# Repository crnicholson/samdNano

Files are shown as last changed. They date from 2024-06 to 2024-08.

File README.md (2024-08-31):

# samdNano+

samdNano+ PCB

The samdNano+ is based on the Arduino Nano board. The format was extended to allow for more pins to be broken out. It uses the powerful SAMD21G18A chip that is significantly faster and more powerful than the Arduino Nano. It boasts extra pins just for SPI and I2C, while additionally the option to disable LEDs and the power regulator for ultra-low power performance. 

# License

samdNano+ is licensed under the CERN Open Hardware Licence Version 2 - Strongly Reciprocal to allow to modify it and make their own.

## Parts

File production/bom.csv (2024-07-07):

Designator | Footprint | Quantity | Value | LCSC Part #
C1, C3, C4, C7, C8 | 0402 | 5 | 100 nF | C1525
C10, C9 | 0805 | 2 | 10 uF | C15850
C2 | 0603 | 1 | 1 uF | C15849
C5, C6 | 0402 | 2 | 22 pF | C1555
D1 | 0805 | 1 | PWR_LED | C84256
D2 | 0603 | 1 | LED | C72038
J1 | PinHeader_2x05_P1.27mm_Vertical_SMD | 1 | J Link
J2 | USB_C_Receptacle_GCT_USB4105-xx-A_16P_TopMnt_Horizontal | 1 | USB-C | C136423
J3 | PinHeader_1x18_P2.54mm_Vertical | 1 | Digital
J4 | PinHeader_1x18_P2.54mm_Vertical | 1 | Analog
JP1 | SolderJumper-2_P1.3mm_Open_RoundedPad1.0x1.5mm | 1 | PWR_EN
JP2 | SolderJumper-2_P1.3mm_Open_RoundedPad1.0x1.5mm | 1 | PWR_LED_EN
JP3 | SolderJumper-2_P1.3mm_Open_RoundedPad1.0x1.5mm | 1 | LED_EN
R1, R2 | 0603 | 2 | 1.8 K | C4177
R3, R5 | 0402 | 2 | 5.1 K | C25905
R4 | 0402 | 1 | 220 | C25091
R6, R7 | 0402 | 2 | 1 K | C11702
SW1 | SW_SPST_CK_RS282G05A3 | 1 | RESET | C2888954
U1 | SOT-223-3_TabPin2 | 1 | AMS1117-3.3 | C6186
U2 | TQFP-48_7x7mm_P0.5mm | 1 | ATSAMD21G18A-A | C78624
Y1 | XTAL_CM7V-T1A-32.768K-12.5PF-20PPM-TA-QA | 1 | 32.768 kHz | C32346

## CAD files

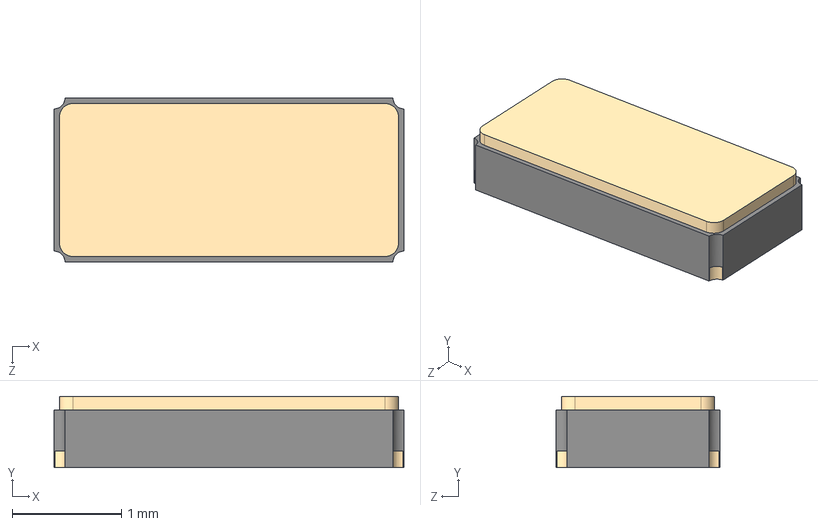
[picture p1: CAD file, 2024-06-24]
CM7V-T1A-32.768K-12.5PF-20PPM-TA-QA/CM7V-T1A-32.768K-12.5PF-20PPM-TA-QA.step
3.20 x 0.65 x 1.50 mm

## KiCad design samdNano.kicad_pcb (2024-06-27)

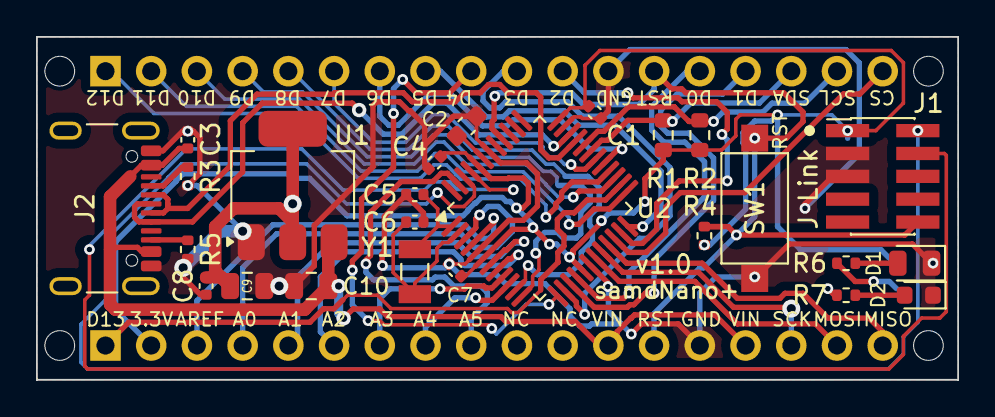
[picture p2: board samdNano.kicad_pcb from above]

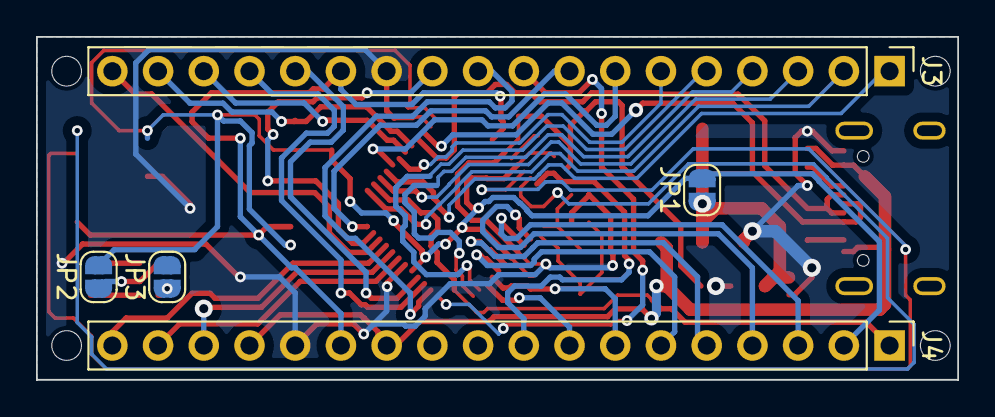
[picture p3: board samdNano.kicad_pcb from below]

Board: 2 copper layers, 51.2 x 19.1 mm, 34 parts (5 on the bottom side), 45 nets.

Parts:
C1, C3, C4, C7, C8: 100 nF; C_0402_1005Metric
C2: 1 uF; C_0603_1608Metric
C5, C6: 22 pF; C_0402_1005Metric
C9, C10: 10 uF; C_0805_2012Metric
D1: PWR_LED; LED_0805_2012Metric
D2: LED; LED_0603_1608Metric
J1: J Link; PinHeader_2x05_P1.27mm_Vertical_SMD
J2: USB-C; USB_C_Receptacle_GCT_USB4105-xx-A_16P_TopMnt_Horizontal
J3: Digital; PinHeader_1x18_P2.54mm_Vertical
J4: Analog; PinHeader_1x18_P2.54mm_Vertical
JP1: PWR_EN; SolderJumper-2_P1.3mm_Open_RoundedPad1.0x1.5mm
JP2: PWR_LED_EN; SolderJumper-2_P1.3mm_Open_RoundedPad1.0x1.5mm
JP3: LED_EN; SolderJumper-2_P1.3mm_Open_RoundedPad1.0x1.5mm
MH1, MH2, MH3, MH4: MountingHole_65mil
R1, R2: 1.8 K; R_0603_1608Metric
R3, R5: 5.1 K; R_0402_1005Metric
R4: 220; R_0402_1005Metric
R6, R7: 1 K; R_0402_1005Metric
SW1: RESET; SW_SPST_CK_RS282G05A3
U1: AMS1117-3.3; SOT-223-3_TabPin2
U2: ATSAMD21G18A-A; TQFP-48_7x7mm_P0.5mm
Y1: 32.768 kHz; XTAL_CM7V-T1A-32.768K-12.5PF-20PPM-TA-QA

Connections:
+3.3V: C1.1, C4.2, C7.1, J1.1, J4.2, JP1.2 (B), JP2.2 (B), R1.2, R2.2, R4.1, U2.6 (VDDANA), U2.17 (VDDIO), U2.36 (VDDIO), U2.44 (VDDIN)
+5V: C3.1, C10.1, J2.A4 (VBUS), J2.A9 (VBUS), J2.B4 (VBUS), J2.B9 (VBUS), J4.12, J4.15, U1.3 (VI)
A0: J4.4, U2.3 (PA02)
A1: J4.5, U2.7 (PB08)
A2: J4.6, U2.8 (PB09)
A3: J4.7, U2.9 (PA04)
A4: J4.8, U2.10 (PA05)
A5: J4.9, U2.47 (PB02)
AREF: J4.3, U2.4 (PA03)
CS: J3.18, U2.22 (PA13)
D0: J3.14, U2.16 (PA11)
D1: J3.15, U2.15 (PA10)
D2: J3.11, U2.23 (PA14)
D3: J3.10, U2.14 (PA09)
D4: J3.9, U2.13 (PA08)
D5: J3.8, U2.24 (PA15)
D6: J3.7, U2.29 (PA20)
D7: J3.6, U2.30 (PA21)
D8: J3.5, U2.11 (PA06)
D9: J3.4, U2.12 (PA07)
D10: J3.3, U2.27 (PA18)
D11: J3.2, U2.25 (PA16)
D12: J3.1, U2.28 (PA19)
D13: J4.1, U2.26 (PA17)
D+: J2.A6 (D+), J2.B6 (D+), U2.34 (PA25)
D-: J2.A7 (D-), J2.B7 (D-), U2.33 (PA24)
GND: C1.2, C2.2, C3.2, C4.1, C5.2, C6.2, C7.2, C8.2, C9.2, C10.2, D1.1 (K), D2.1 (K), J1.3, J1.5, J2.A1 (GND), J2.A12 (GND), J2.B1 (GND), J2.B12 (GND), J3.12, J4.14, R3.2, R5.2, SW1.1, U1.1 (GND), U2.5 (GNDANA), U2.18 (GND), U2.35 (GND), U2.42 (GND)
MISO: J4.18, U2.21 (PA12)
MOSI: J4.17, U2.19 (PB10)
unnamed: D2.2 (A), R7.1
unnamed: D1.2 (A), R6.1
unnamed: J2.A5 (CC1), R3.1
unnamed: J2.B5 (CC2), R5.1
unnamed: C8.1, C9.1, JP1.1 (A), U1.2 (VO)
unnamed: JP3.1 (A), R7.2
unnamed: JP2.1 (A), R6.2
unnamed: C2.1, U2.43 (VDDCORE)
RST: J1.10, J3.13, J4.13, R4.2, SW1.2, U2.40 (~RESET)
SCK: J4.16, U2.20 (PB11)
SCL: J3.17, R2.1, U2.32 (PA23)
SDA: J3.16, R1.1, U2.31 (PA22)
SWCLK: J1.4, U2.45 (PA30)
SWDIO: J1.2, U2.46 (PA31)
XIN: C5.1, U2.1 (PA00), Y1.1
XOUT: C6.1, U2.2 (PA01), Y1.2

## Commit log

2024-06-24 Basic layout
    [CM7V-T1A-32.768K-12.5PF-20PPM-TA-QA.step, samdNano.kicad_pcb, samdNano.kicad_sch]
2024-06-27 almost finished board
    [samdNano.kicad_pcb]
2024-07-07 Finished board and silkscreen
    [bom.csv, designators.csv, positions.csv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]
